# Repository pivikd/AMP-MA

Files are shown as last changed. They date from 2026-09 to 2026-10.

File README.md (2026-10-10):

<p align="center">
   
   
</p><p align="center">
   
   
</p>

# Project Status

   **AMP-AM is currently in the early development phase and is considered unstable. The first stable release is scheduled for Q3 2026**
   
   **The project is currently in the pre-alpha stage – creating the first prototype**

# AMP-AM (AMP Modus Aequale)

AMP-AM (standing for Modus Aequale, signifying a rhythmic, ideal tone and modular structure) is an open-source, transistor-based guitar combo amplifier project. It is designed to bridge the gap between solid-state reliability and the organic, harmonic richness of vacuum tube sound.

The project focuses on a modular architecture, originally developed as a high-fidelity upgrade for the **Epiphone 15C** PCB. By utilizing independent blocks, AMP-AM allows for seamless customization and easier adaptation to various amp enclosures.

This project is designed and maintained by: [Danylo Pyvovarov](https://github.com/pivikd).

   1. [Key Features](#key-features)
   1. [Signal Chain](#signal-chain)
   <!-- 1. [Integrated Effects Modules](#integrated-effects-modules) -->

## Key Features
   - **Tube-like Architecture**: Uses **Mu-amp**  based cascades with **2SK30A**  transistors to achieve a warm, organic sound and harmonic saturation that mimics vacuum tube behavior.

   - **Dual Input Support**: Designed to handle two guitars simultaneously.

   - **Legendary Tone Stack**: Features a 3-band EQ based on the classic **Marshall JCM900 2100 SL-X preamp**.

   - **Integrated Compression**: Built-in compressor block based on the vintage **Ibanez CP835** circuitry.

   <!-- - **Modular Design**: Optimized for easy integration into different amp cabinets or for swapping internal effect modules. -->

## Signal Chain
   1. Input buffer
   1. Preamp ([Mu-AMP](https://www.muzique.com/amz/mini.htm))
   1. Compressor ([Ibanez CP835](https://www.scribd.com/document/976348354/Ibanez-CP835-Schematic))
   1. Tone Stack ([JCM900 2100 SL-X](https://stompboxelectronics.com/2023/12/16/the-marshall-tone-stacks/))
   1. Recovery Stage
   1. Power Amp ([LM1875](https://www.ti.com/lit/ds/symlink/lm1875.pdf))

<!-- ## Integrated Effects Modules
| Effect | based on |  Satus  |
|---|---|---|
| Compressor | Ibanez CP835 |  done |
<!-- | Over Drive        | Boss OD3     | planed  |
| Chorus            | Boss Ch1     | planed  | -->

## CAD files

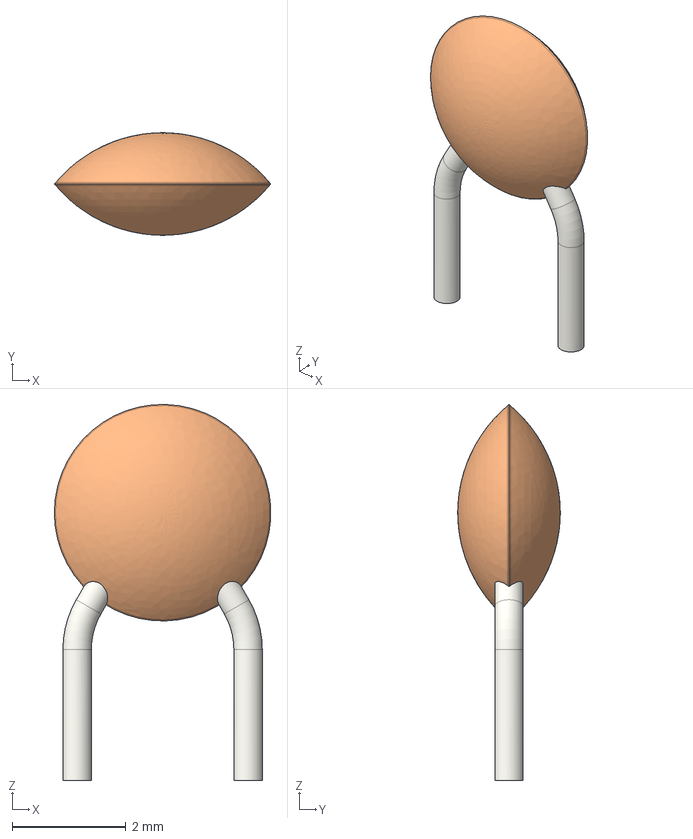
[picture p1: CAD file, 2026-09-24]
PrLib/3D/C_disc_D3.8_W1.8_P3.step
3.80 x 1.80 x 6.60 mm

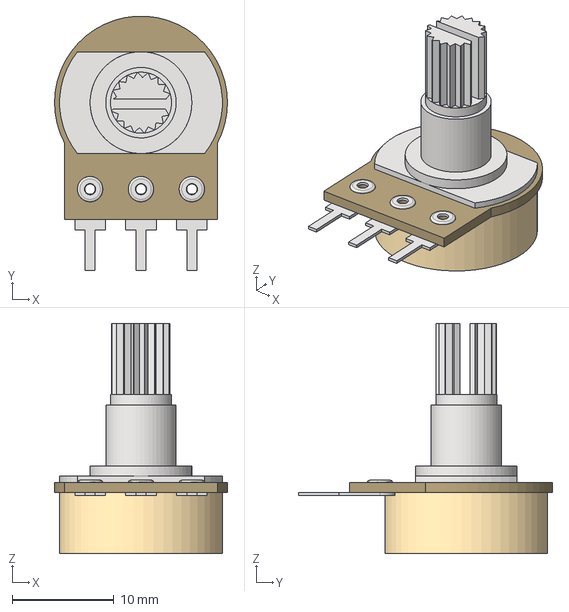
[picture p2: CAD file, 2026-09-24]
PrLib/3D/potentiometer.step
17.0 x 25.0 x 22.6 mm

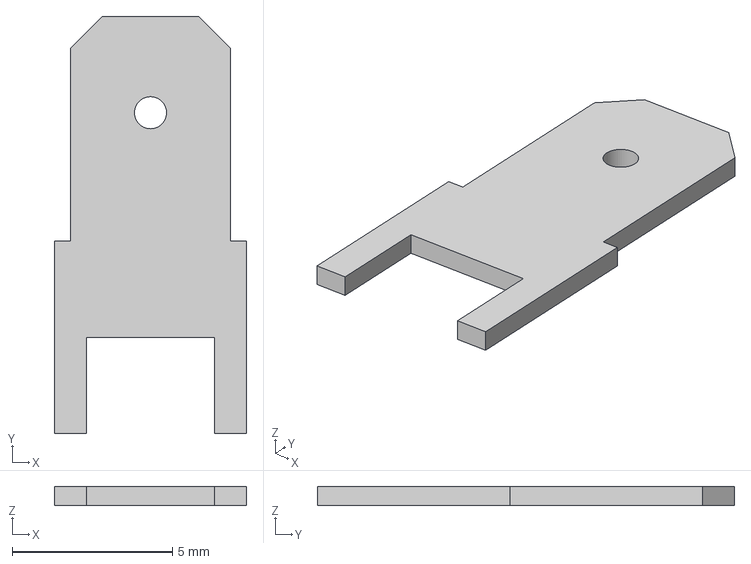
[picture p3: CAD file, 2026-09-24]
PrLib/3D/conector.step
6.00 x 13.0 x 0.6 mm

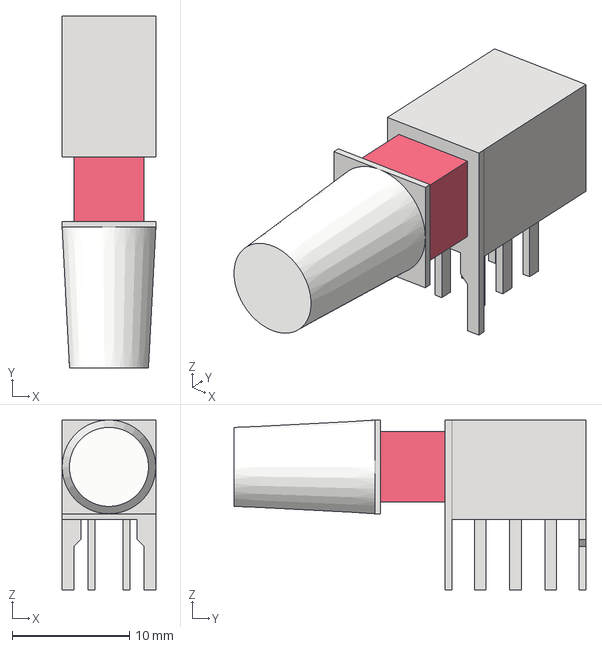
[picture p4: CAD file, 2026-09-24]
PrLib/3D/switch.step
8.00 x 30.0 x 14.5 mm

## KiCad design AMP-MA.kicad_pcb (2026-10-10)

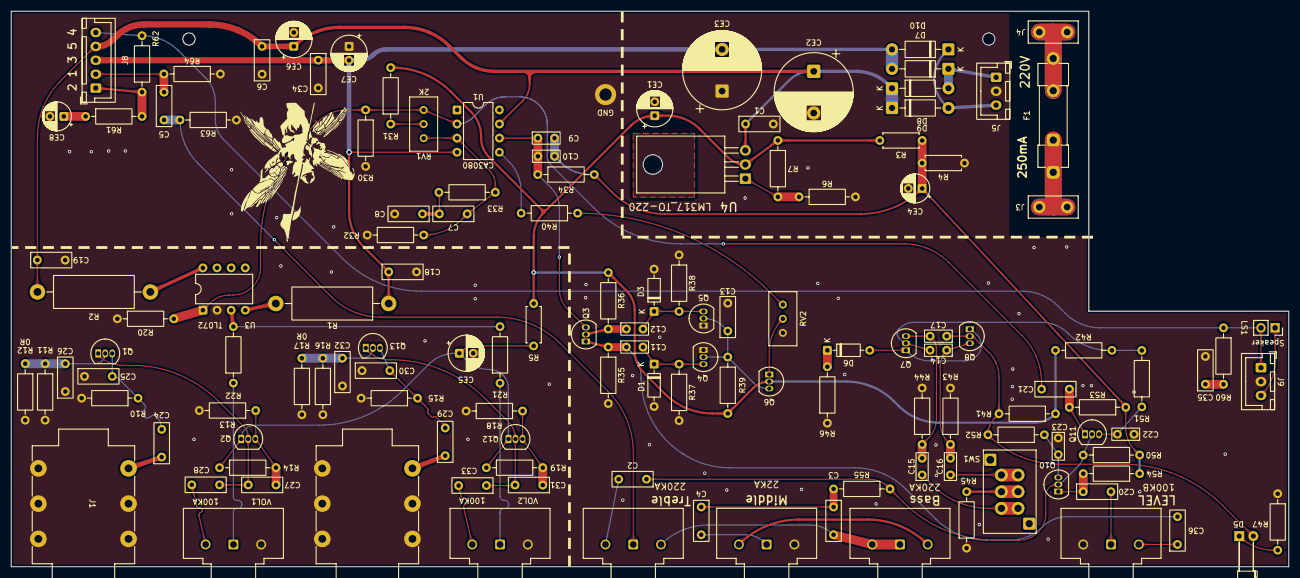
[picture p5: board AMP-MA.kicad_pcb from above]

Board: 2 copper layers, 230.0 x 100.0 mm, 137 parts (0 on the bottom side), 70 nets.

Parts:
Bass: 220KA; potentiometer
C1, C18, C19, C20, C21, C36: 100n; C_disc_D7_W2.5_P5
C2: 470p; C_disc_D7_W2.5_P5
C3, C4: 22n; C_disc_D7_W2.5_P5
C5: 2.2u; C_disc_D7_W2.5_P5
C6, C34: 0.1u; C_disc_D7_W2.5_P5
C7: 10n; C_disc_D7_W2.5_P5
C8: 1u/10; C_disc_D7_W2.5_P5
C9, C10, C14, C15, C16, C17: 1n; C_Disc_D4.3_W1.9_P5.00
C11, C12, C22, C23: 10n; C_Disc_D4.3_W1.9_P5.00
C13: 10u/16; C_disc_D7_W2.5_P5
C24, C29: 50n; C_disc_D7_W2.5_P5
C25, C30: 10p; C_disc_D7_W2.5_P5
C26, C32: 10u; C_disc_D7_W2.5_P5
C27, C31: 3.3u; C_disc_D7_W2.5_P5
C28, C33, C35: 220n; C_disc_D7_W2.5_P5
CE1, CE5, CE6, CE7: 100u; CP_Radial_D6.3mm_P2.50mm
CE2, CE3: 2200u; CP_Radial_D14.0mm_P7.50mm
CE4: 47u; CP_Radial_D5.0mm_P2.50mm
CE8: 22u; CP_Radial_D5.0mm_P2.50mm
D1, D3, D6: 1N914; D_DO-35_SOD27_P7.62mm_Horizontal
D5: LED; LED_D3.0mm_Horizontal_O6.35mm_Z6.0mm
D7, D8, D9, D10: 1N4007; D_DO-41_SOD81_P10.16mm_Horizontal
F1: 250mA; Fuseholder_Clip-5x20mm_Littelfuse_520_Inline_P20.50x5.80mm_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
GND: MountingHole_Pad; MountingHole_2.2mm_M2_DIN965_Pad
H1, H2: MountingHole; MountingHole_2.2mm_M2
J1, J2: Jack_3_6pin
J3: Phase; connector
J4: PX Ph; connector
J5: PXB10C; JST_XH_B3B-XH-A_1x03_P2.50mm_Vertical
J8: Socket_01x05; JST_XH_B5B-XH-A_1x05_P2.50mm_Vertical
J9: Socket_01x03; JST_XH_B3B-XH-A_1x03_P2.50mm_Vertical
LEVEL: 100KB; potentiometer
LS1: Speaker; PinSocket_1x02_P2.54mm_Vertical
Middle: 22KA; potentiometer
Q1, Q2, Q12, Q13: 2N5484; TO-92_Inline
Q3, Q4, Q5, Q6, Q7, Q8: 2SC1815; TO-92_Inline
Q10, Q11: J201; TO-92_Inline
R1, R2: 220R; R_Axial_DIN0614_L14.3mm_D5.7mm_P20.32mm_Horizontal
R3, R4: 10K; R_Axial_DIN0207_L6.3mm_D2.5mm_P7.62mm_Horizontal
R5: 100; R_Axial_DIN0207_L6.3mm_D2.5mm_P7.62mm_Horizontal
R6: 2K; R_Axial_DIN0207_L6.3mm_D2.5mm_P10.16mm_Horizontal
R7: 240R; R_Axial_DIN0207_L6.3mm_D2.5mm_P10.16mm_Horizontal
R10, R13, R14, R15, R18, R19, R30, R32, R37, R38, R51, R52, R63: 1M; R_Axial_DIN0207_L6.3mm_D2.5mm_P10.16mm_Horizontal
R11, R16, R61: 1K; R_Axial_DIN0207_L6.3mm_D2.5mm_P10.16mm_Horizontal
R12, R17: 0R; R_Axial_DIN0207_L6.3mm_D2.5mm_P10.16mm_Horizontal
R20, R21, R22: 4K7; R_Axial_DIN0207_L6.3mm_D2.5mm_P10.16mm_Horizontal
R31: 470K; R_Axial_DIN0207_L6.3mm_D2.5mm_P10.16mm_Horizontal
R33, R35, R36, R41, R42: 10K; R_Axial_DIN0207_L6.3mm_D2.5mm_P10.16mm_Horizontal
R34, R39: 150K; R_Axial_DIN0207_L6.3mm_D2.5mm_P10.16mm_Horizontal
R40: 20K; R_Axial_DIN0207_L6.3mm_D2.5mm_P10.16mm_Horizontal
R43, R44: 56K; R_Axial_DIN0207_L6.3mm_D2.5mm_P10.16mm_Horizontal
R45: 22R; R_Axial_DIN0207_L6.3mm_D2.5mm_P10.16mm_Horizontal
R46: 100R; R_Axial_DIN0207_L6.3mm_D2.5mm_P10.16mm_Horizontal
R47: 800R; R_Axial_DIN0207_L6.3mm_D2.5mm_P10.16mm_Horizontal
R50, R53, R54: 510K; R_Axial_DIN0207_L6.3mm_D2.5mm_P10.16mm_Horizontal
R55: 33K; R_Axial_DIN0207_L6.3mm_D2.5mm_P10.16mm_Horizontal
R60: 1R; R_Axial_DIN0207_L6.3mm_D2.5mm_P10.16mm_Horizontal
R62, R64: 22K; R_Axial_DIN0207_L6.3mm_D2.5mm_P10.16mm_Horizontal
RV1: 2K; Potentiometer_Bourns_3296W_Vertical
RV2: 500KC; Potentiometer_Bourns_3296W_Vertical
SW1: SW_DPDT_x2; SW DPDT
Treble: 220KA; potentiometer
U1: CA3080; DIP-8_W7.62mm
U3: TL072; DIP-8_W7.62mm
U4: LM317_TO-220; TO-220-3_Horizontal_TabDown
VOL1, VOL2: 100KA; potentiometer

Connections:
/Compression block/BIAS: R40.2, U1.5 (BIAS)
/Compression block/BP_OUT: C17.1, D5.2 (A), Q8.2 (C), R41.2, R52.2
/Compression block/CP_IN: C11.1, C36.2, Q3.1 (E), R35.1
/Compression block/EFF_OUT: C14.2, Q7.2 (C), R42.2, R51.2
/LM_IN+: C5.2, J8.2, R64.2
/LM_IN-: J8.1, R61.2, R62.1
/LM_OUT: J8.5, J9.1, LS1.2, R60.1, R62.2
/PREAMP1: R22.1, VOL1.2
/PREAMP2: R21.1, VOL2.2
/ToneSt: C5.1, R63.2, Treble.2
CP_OUT: C2.1, Q10.2 (S), Q11.2 (S), R50.2, R55.2
GND: C1.2, C6.1, C8.2, C13.2, C18.2, C19.2, C22.1, C23.1, C25.1, C26.1, C30.1, C32.1, C34.2, C35.2, CE1.2, CE2.2, CE3.1, CE4.2, CE5.2, CE6.2, CE7.1, CE8.2, D1.2 (A), D3.2 (A), GND.1 (1_1), J1.R, J1.RN, J1.S, J1.SN, J1.TN, J2.R, J2.RN, J2.S, J2.SN, J2.TN, J5.2, J9.2, LEVEL.1, Middle.3, Q4.1 (E), Q5.1 (E), R4.2, R6.2, R10.2, R11.2, R12.2, R13.2, R15.2, R16.2, R17.2, R18.2, R20.1, R30.2, R32.2, R35.2, R37.2, R38.1, R43.2, R44.2, R45.1, R46.1, R47.1, R63.1, R64.1, RV2.1, U3.2 (-), VOL1.3, VOL2.3
unnamed: Bass.1, Bass.2, C3.2, Treble.3
unnamed: Bass.3, Middle.1
unnamed: C2.2, Treble.1
unnamed: C3.1, C4.1, R55.1
unnamed: C4.2, Middle.2
unnamed: C7.2, C8.1, R33.2
unnamed: C20.2, LEVEL.2
unnamed: C24.1, J1.T
unnamed: C28.2, VOL1.1
unnamed: C29.1, J2.T
unnamed: C33.2, VOL2.1
unnamed: C35.1, R60.2
unnamed: C36.1, LEVEL.3
unnamed: CE8.1, R61.1
unnamed: C11.2, D1.1 (K), Q4.3 (B), R37.1
unnamed: C12.2, D3.1 (K), Q5.3 (B), R38.2
unnamed: D5.1 (K), R47.2
unnamed: D6.2 (A), Q7.1 (E), Q8.1 (E)
unnamed: D6.1 (K), R46.2
unnamed: D7.1 (K), D8.2 (A), J5.1
unnamed: D9.2 (A), D10.1 (K), J5.3
unnamed: F1.1, J3.1 (Pin_1_1)
unnamed: F1.2, J4.1 (Pin_1_1)
unnamed: J9.3, LS1.1
unnamed: C27.2, C28.1, Q1.1 (D), Q2.2 (S)
unnamed: C24.2, C25.2, Q1.3 (G), R10.1
unnamed: C26.2, Q1.2 (S), R11.1, R12.1
unnamed: C27.1, Q2.3 (G), R13.1, R14.2
unnamed: C9.1, C10.1, Q3.3 (B), R34.1, U1.6
unnamed: C12.1, Q3.2 (C), R36.2
unnamed: C13.1, Q4.2 (C), Q5.2 (C), Q6.3 (B), R39.1
unnamed: Q6.1 (E), RV2.2
unnamed: C15.2, C17.2, Q7.3 (B), R44.1
unnamed: C14.1, C16.2, Q8.3 (B), R43.1
unnamed: C20.1, Q10.1 (D), R54.2
unnamed: C23.2, Q10.3 (G), R52.1
unnamed: C21.2, Q11.1 (D), R53.2
unnamed: C22.2, Q11.3 (G), R51.1
unnamed: C31.1, Q12.3 (G), R18.1, R19.2
unnamed: C31.2, C33.1, Q12.2 (S), Q13.1 (D)
unnamed: C29.2, C30.2, Q13.3 (G), R15.1
unnamed: C32.2, Q13.2 (S), R16.1, R17.1
unnamed: R31.1, RV1.2
unnamed: R40.1, RV2.3
unnamed: C16.1, SW1.1 (A), SW1.4 (A)
unnamed: R45.2, SW1.2 (B), SW1.5 (B)
unnamed: C15.1, SW1.3 (C), SW1.6 (C)
unnamed: C7.1, R32.1, R33.1, RV1.1, U1.3 (+)
unnamed: R21.2, R22.2, U3.3 (+)
unnamed: R2.2, U3.8 (V+)
unnamed: R1.2, U3.4 (V-)
unnamed: R6.1, R7.2, U4.1 (ADJ)
PREAMP: C21.1, R20.2, R30.1, RV1.3, U1.2 (-), U3.1
VB: C9.2, C10.2, CE4.1, R3.2, R4.1, R34.2, R50.1, R53.1, R54.1
VC: CE1.1, Q6.2 (C), R3.1, R5.2, R7.1, R31.2, R36.1, R39.2, R41.1, R42.1, U4.2 (VO)
VCC: C1.1, C6.2, C19.1, CE2.1, CE6.1, D8.1 (K), D9.1 (K), J8.4, R2.1, U1.7 (V+), U4.3 (VI)
VEE: C18.1, C34.1, CE3.2, CE7.2, D7.2 (A), D10.2 (A), J8.3, R1.1, U1.4 (V-)
VMu: CE5.1, Q2.1 (D), Q12.1 (D), R5.1, R14.1, R19.1

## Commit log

2026-04-23 Init commit
    [AMP_DP0.kicad_pcb, AMP_DP0.kicad_sch]
2026-04-23 Schem upd
    added Copressor module
    [AMP_DP0.kicad_sch, Cp.kicad_sch]
2026-04-24 Schem upd
    added Voltage supply
    [AMP_DP0.kicad_sch, Cp.kicad_sch, PwSup.kicad_sch]
2026-04-26 Schem & lib upd
    added audiojack symbol & added PREAMP cascade
    [AMP_DP0.kicad_sch, PwSup.kicad_sch]
2026-04-27 Project renamed
    [AMP-MA.kicad_pcb, AMP-MA.kicad_sch, AMP_DP0.kicad_pcb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]
2026-04-28 Schem & Lib upd
    Lib: added footprint and Symbol foe new 6pin jack Schem: changed jacks
    [AMP-MA.kicad_sch, Cp.kicad_sch, ToneSt.kicad_sch]
2026-04-29 Schem upd
    Tone Stack addded
    [AMP-MA.kicad_sch, Cp.kicad_sch]
2026-04-30 Schem & README upd
    added AMP block
    [AMP-MA.kicad_sch]
2026-05-02 power supply upd
    9v pover supply changed on AC-DC tancformer
    [PwSup.kicad_sch]
2026-05-03 Big upd
    moved hierarical Sheets to direсtory Schematics, revorked power supply
    [AMP-MA.kicad_sch, Cp.kicad_sch, PwSup.kicad_sch]
2026-05-03 footprints assigned
    [AMP-MA.kicad_sch, Cp.kicad_sch, PwSup.kicad_sch]
2026-05-04 directory cleared, Schem upd
    The input mixer changed from passive to active(TL072)
    [AMP-MA.kicad_sch, Cp.kicad_sch, PwSup.kicad_sch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]
2026-05-05 Schem upd
    in bypass button changed on SPDT switch
    [Cp.kicad_sch]
2026-05-06 Schem upd
    The LED is powered by the low voltage supply, not by the effect
    [Cp.kicad_sch, PwSup.kicad_sch]
2026-05-06 Schem upd
    Managed power supply for TL072
    [Cp.kicad_sch, PwSup.kicad_sch]
2026-05-07 Schem upd & added .gitignore
    [AMP-MA.kicad_sch, PwSup.kicad_sch]
2026-05-11 Lib & Schematic upd
    Jack connector symbol update. Made basic layout has been made
    [AMP-MA.kicad_pcb, AMP-MA.kicad_sch, Cp.kicad_sch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]
2026-05-18 smal schem upd
    [AMP-MA.kicad_sch, Cp.kicad_sch]
2026-09-04 PCB and Schem upd
    [AMP-MA.kicad_pcb, AMP-MA.kicad_sch, Cp.kicad_sch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]
2026-09-22 Big upd
    fully routed pcb. Some small updates for Schematic
    [AMP-MA.kicad_pcb, AMP-MA.kicad_sch, Cp.kicad_sch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]
2026-09-24 small upd
    changed & added capacitor footprint. replaced potentimeters
    [AMP-MA.kicad_pcb, AMP-MA.kicad_sch, C_disc_D3.8_W1.8_P3.step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]
2026-09-24 First Beta
    [AMP-MA.kicad_pcb, AMP-MA.kicad_sch, Cp.kicad_sch]
2026-10-10 Dev(#4)
    * Patch 0
    PCB updates
    * Patch 1
    Major PCB update
    * Delete AMP-MA-backups directory
    * Patch 2 gitignore update
    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
    [AMP-MA.kicad_pcb, AMP-MA.kicad_sch, Cp.kicad_sch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]
2026-10-22 0.1 Release (#6)
    * feat: start version 0.1.0 development
    Schemati upd: Revorked Power supply module
    * Schematic upd
    Revorked bypass module, Annotated capacitors, Replaced 2N5484 and j209 with 2SK30A
    * Schematic upd
    Revorked mix module, Bypass upd, Replaced 1N914 with 1N4148
    * Big Upd
    Schemaics: Tone Stack moved to differend file and made some differend variants of, reassigned some footprints
    Readme upd: added tone stacks types
    * Cosmetic upd
    * Change license from GPL to CERN OHL v2
    Replaced GNU General Public License with CERN Open Hardware Licence Version 2 - Strongly Reciprocal. Updated terms and conditions to reflect the new licensing framework.
    * Schem. & Readme upd
    volume c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

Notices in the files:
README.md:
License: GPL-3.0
